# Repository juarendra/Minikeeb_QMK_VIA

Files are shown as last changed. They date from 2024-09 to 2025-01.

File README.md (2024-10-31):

# Minikeeb
a split keyboard mini based on microdox and microredox using MX Style Switch 

## Table of Content
* [Product Specsification](#product-specsification)
* [Download VIA](#download-via)
* [Load JSON File](#Load-JSON-File)
* [Link Keycode QMK](#Link-keycode-qmk)
* [Tutorial VIA Usage](#tutorial-via-usage)
* [Cara Setting Knob](#cara-setting-knob)
* [How To use MACRO](#how-to-use-macro)
* [Preview Hardware](#preview-hardware)
* [Preview VIA](#preview-via)
* [Cara Update/Upgrade Firmware](#cara-update/upgrade-firmware)
* [Documentation](#documentation)
  * [Pinout Diagram](#pinout-diagram)
  * [Dimension](#dimension)
  * [BOM](#bom)
  * [Schematic](#schematic)
  * [Example Program](#examples-program)
* [FAQ](#FAQ)

## Product Specsification
- Arduino Pro Micro Type C as Microcontroller
- QMK Firmware
- Support VIA, all key and knob can proggrammed
- RGB per Keys
- 4x Layer 
- Hotswap Switch
- 3D Case 

## Download VIA
Link Download VIA(CHOSEE BASED YOUR OS) : https://github.com/the-via/releases/releases
VIA WEB VERSION : https://usevia.app/

## Link Keycode QMK
- mouse : https://github.com/qmk/qmk_firmware/blob/master/docs/feature_mouse_keys.md
- keyboard : https://github.com/qmk/qmk_firmware/blob/master/docs/keycodes.md

## Tutorial VIA Usage
- https://docs.keeb.io/via

## Cara Setting Knob
- Untuk melakukan setting di knob perlu memasukan command berupa keycode qmk, Jadi cara nya sama dengan melakuykan setting dengan Any key seperti petunjuk pada link berikut: 
https://docs.keeb.io/via

Here's some examples:

- LALT(KC_TAB) - Sends Alt-Tab
- LCTL(KC_C) - Sends Ctrl-C
- LGUI(KC_C) - Sends Cmd-C or Win-C
- LSFT(LCTL(KC_END)) - Sends Shift-Ctrl-End
- MO(1) - Momentarily turn on layer 1
- LCA(KC_DEL) - Sends Ctrl-Alt-Del
- MT(MOD_RSFT, KC_ENT) - Sends Shift if held, Enter if tapped
- MACRO (0) - macro 0

## How To use MACRO
you can read on [this file](https://github.com/juarendra/STREAMPAD-QMK-VIA/blob/main/DOC/MACRO%20VIA%20USAGE.pdf)
or you can read on this [web](https://www.keychron.com/blogs/archived/how-to-use-via-to-program-your-keyboard)
or you can see video [youtube](https://youtu.be/GtSeo69Y0Zw)

## Preview Hardware
<p align="center">
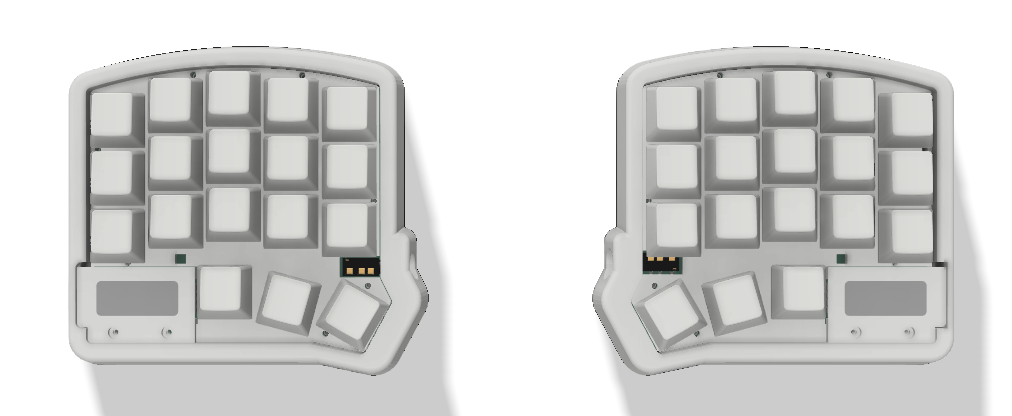
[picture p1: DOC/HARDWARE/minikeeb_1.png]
  
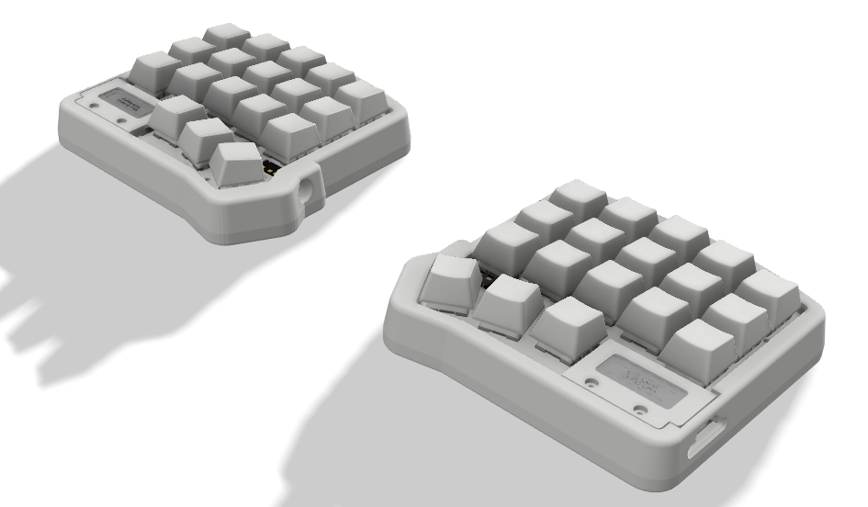
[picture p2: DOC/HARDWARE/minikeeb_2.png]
  
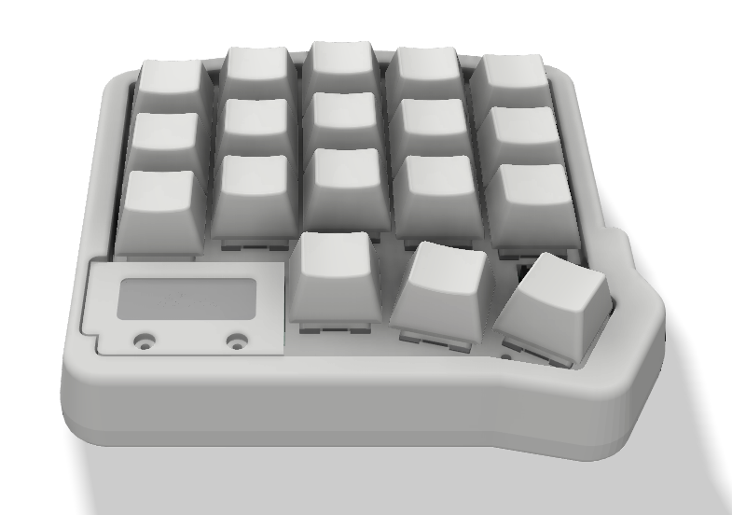
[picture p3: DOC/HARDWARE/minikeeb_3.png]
  
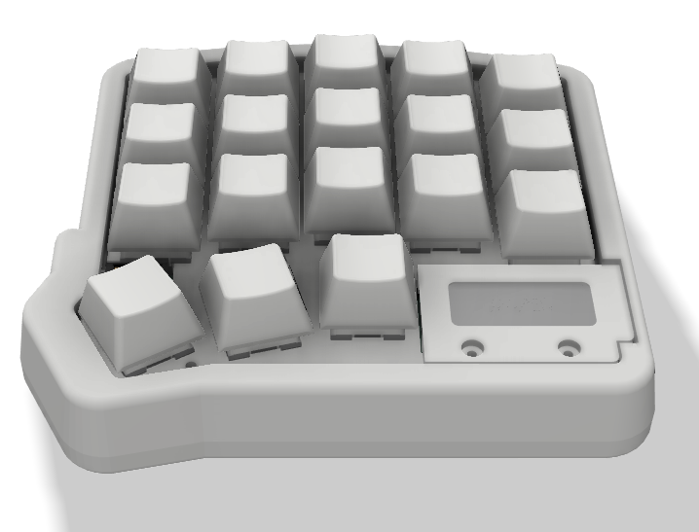
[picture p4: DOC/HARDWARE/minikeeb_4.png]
  
</p>

## Preview VIA

https://github.com/juarendra/Zeapad-Pro-QMK-VIA/assets/43043633/afd7e68e-0a54-4b18-be12-b96c0f13611a

## Cara Update/Upgrade Firmware
- Siapkan dahulu Keyboard minikeeb, kabel usb dan firmware yang ingin di update/upgrade ke keyboard anda anda
- Anda perlu melakukan flashing di masing masing sisi keyboard (kanan dan kiri)
- Siapkan Firmware yang akan digunakan untuk update/upgrade
- Download Software QMK Toolbox di [link berikut](https://github.com/qmk/qmk_toolbox/releases)
- Install Software QMK Toolbox, Install Semua drivernya. setelah siap anda dapat meload Firmware yang seblumnya. Lalu Centang Auto-Flash seperti gambar dibawah
<p align="center">
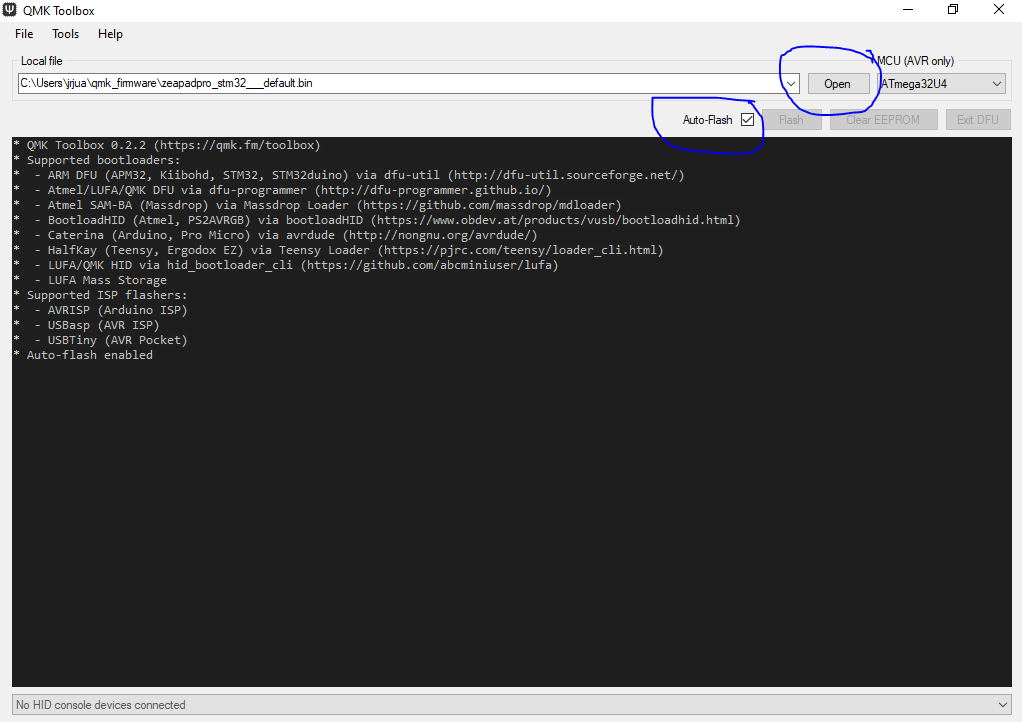
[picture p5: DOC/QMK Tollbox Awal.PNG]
  
</p>

- Lakukan flashing pada sisi kiri dahulu
- Pada minikeeb sisi kiri Colok kabel ujung usb type C ke keyboard tanpa mencolokannya dahulu ke USB PC anda
- Tekan dan tahan tombol yang berada di ujung atas kiri. lalu colokan Ujung USB yang sebelum ke USB PC anda sambil tetap menahan tombol sebelum nya sebentar
- Setelah ada bunyi/notif USB masuk. anda dapat melepaskan tombol/knobnya
- Maka secara otomatis macropad akan terflash. jika selesai maka tampilan QMK toolbox akan seperti gambar dibawah
<p align="center">
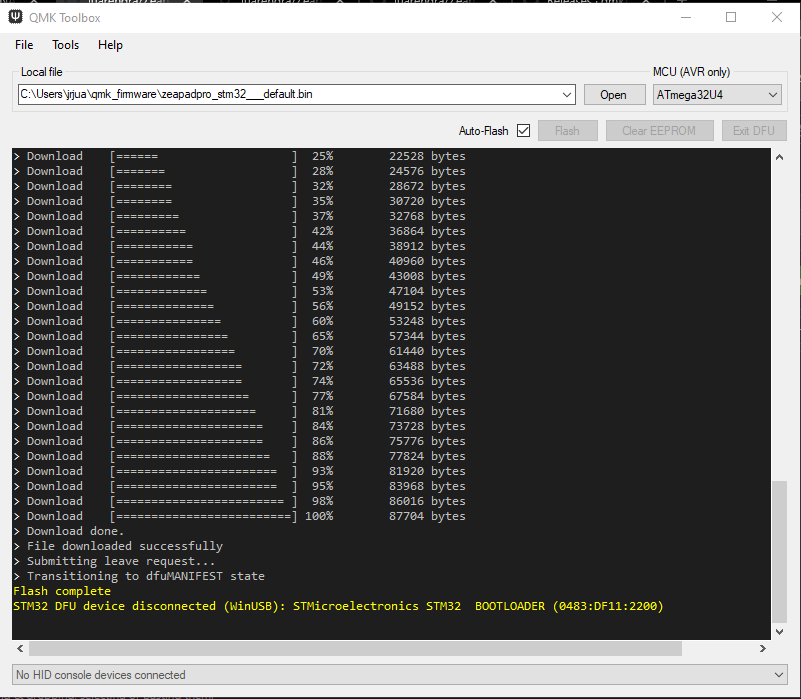
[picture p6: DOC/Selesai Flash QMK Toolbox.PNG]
  
</p>

- Lakukan flashing pada sisi kanan
- Pada minikeeb sisi kanan Colok kabel ujung usb type C ke keyboard tanpa mencolokannya dahulu ke USB PC anda
- Tekan dan tahan tombol yang berada di ujung atas kanan. lalu colokan Ujung USB yang sebelum ke USB PC anda sambil tetap menahan tombol sebelum nya sebentar
- Setelah ada bunyi/notif USB masuk. anda dapat melepaskan tombol/knobnya
- Maka secara otomatis macropad akan terflash. jika selesai maka tampilan QMK toolbox akan seperti gambar dibawah
<p align="center">
  
</p>

## Documentation
### Pinout Diagram
### Dimension
[Dimension File](https://github.com/juarendra/Minikeeb_QMK_VIA/blob/main/HARDWARE/dimension%20minikeeb.pdf)
### BOM
### Schematic
[Schematic File](https://github.com/juarendra/Minikeeb_QMK_VIA/blob/main/HARDWARE/schematic%20minikeeb.pdf)
### Example Program
[Example Firmware]()
## FAQ

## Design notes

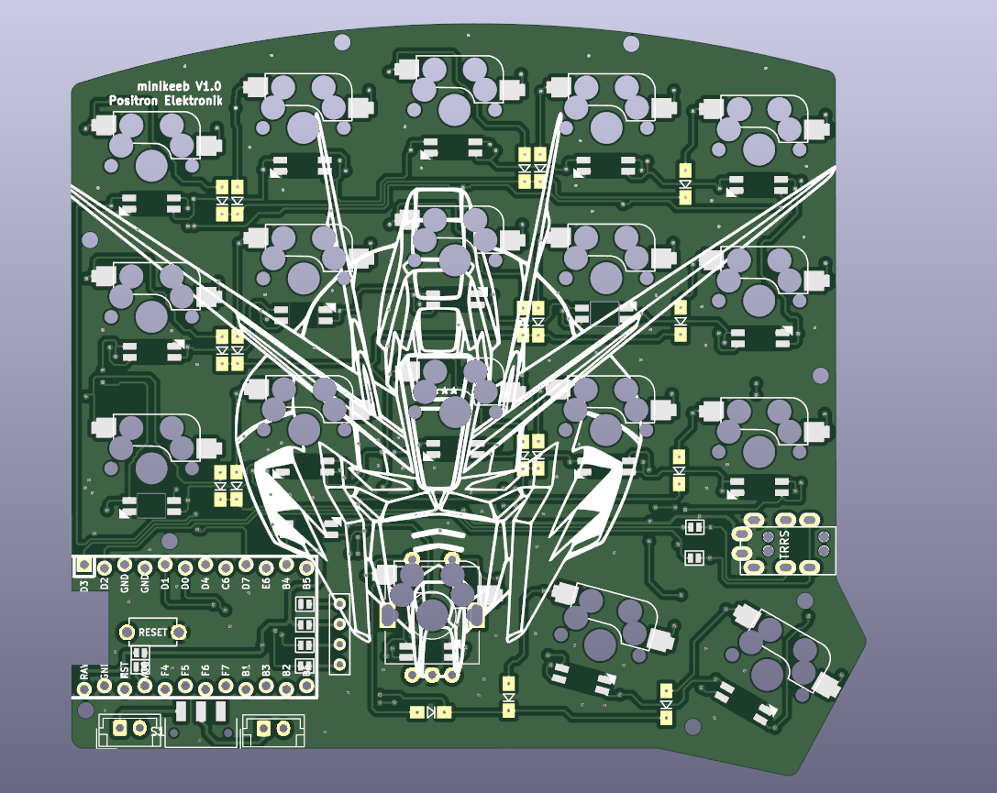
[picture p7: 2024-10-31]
DOC/HARDWARE/minikeeb_PCB.png

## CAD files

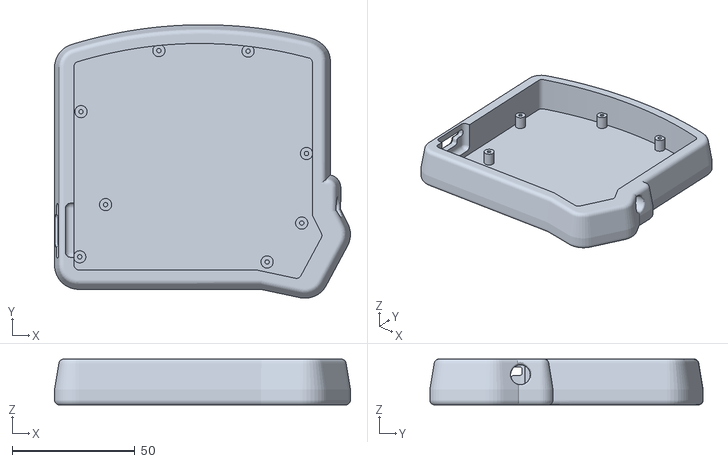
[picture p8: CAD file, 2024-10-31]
HARDWARE/3D CASE/left/minikeeb_bottom left.stl
120.5 x 111.3 x 18.7

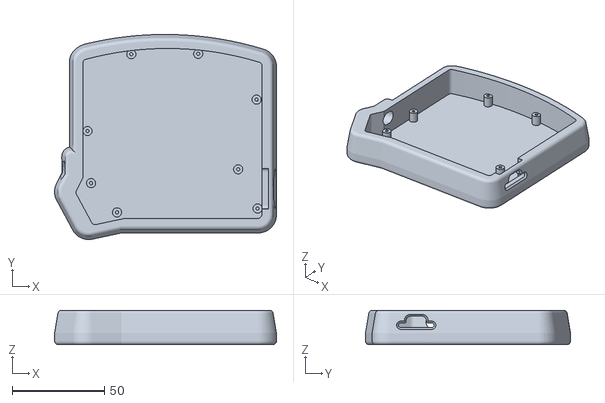
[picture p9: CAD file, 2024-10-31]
HARDWARE/3D CASE/right/minikeeb_bottom right.stl
120.5 x 111.3 x 18.7

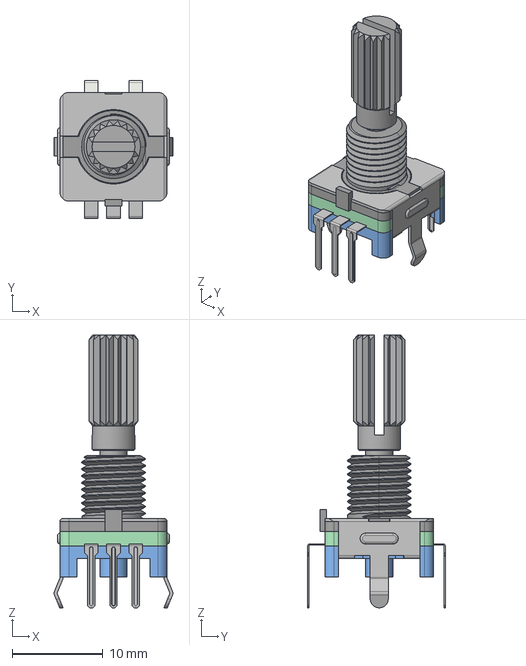
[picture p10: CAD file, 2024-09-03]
SCH-PCB/PCB/minikeeb/3d/EC11_Rotary_Encoder_Switched.step
13.1 x 15.3 x 30.1 mm

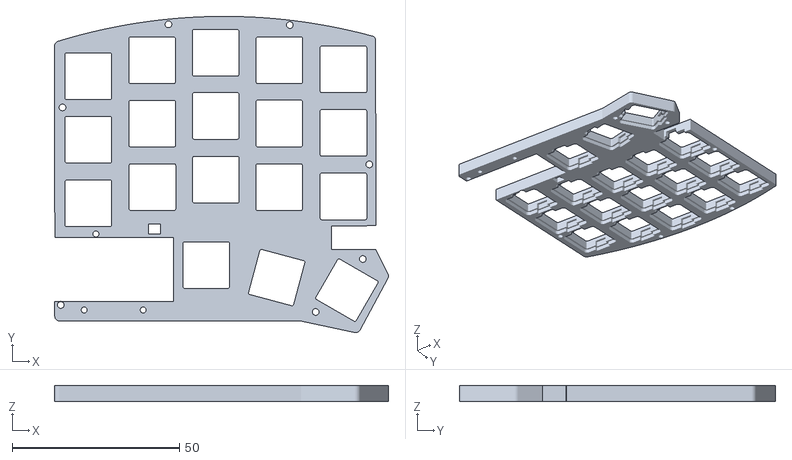
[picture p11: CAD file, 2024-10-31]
HARDWARE/3D CASE/left/minikeeb_plate left.stl
99.9 x 94.6 x 4.80

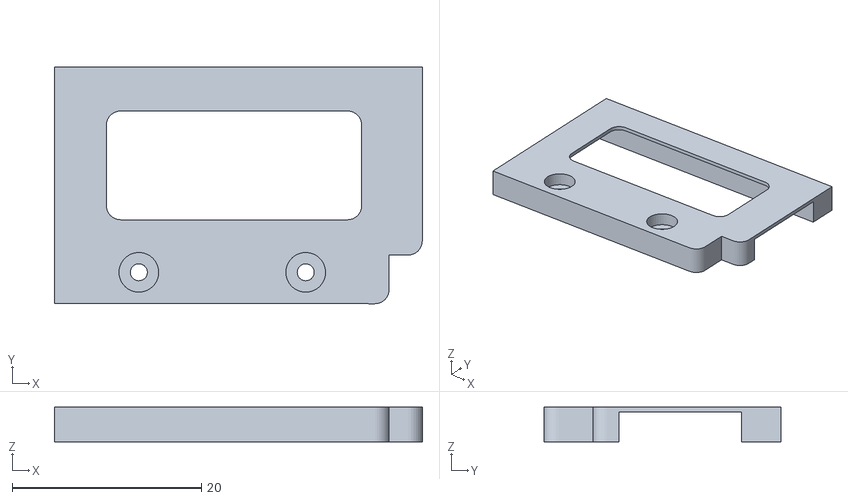
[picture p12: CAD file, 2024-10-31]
HARDWARE/3D CASE/right/minikeeb_cover oled right.stl
38.9 x 25.0 x 3.69

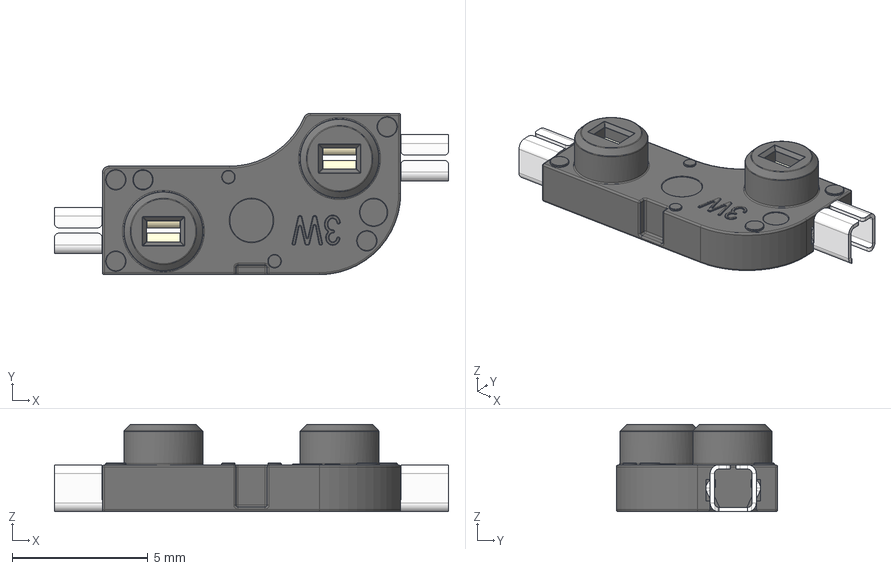
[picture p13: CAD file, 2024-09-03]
SCH-PCB/PCB/minikeeb/3d/Kailh Hotswap MX v22.step
14.5 x 5.95 x 3.22 mm

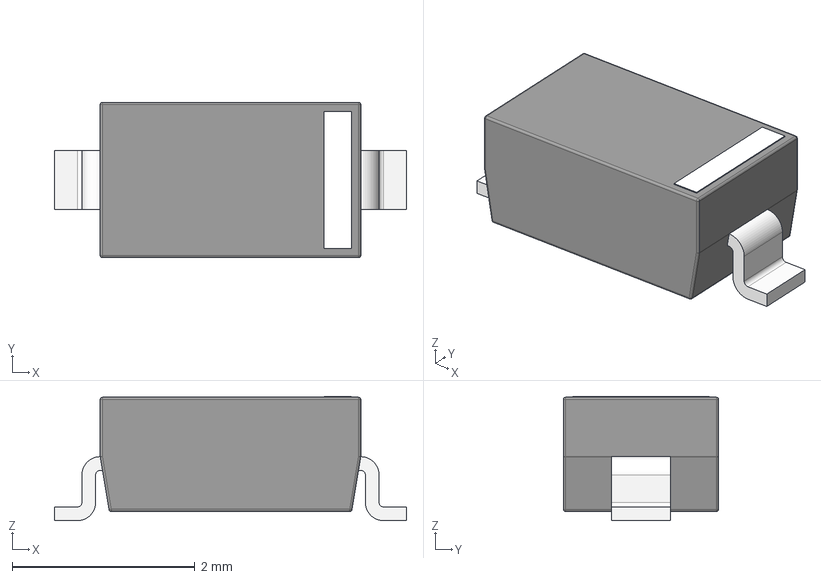
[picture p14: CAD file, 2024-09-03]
SCH-PCB/PCB/minikeeb/3d/SOD-123.step
3.85 x 1.70 x 1.36 mm

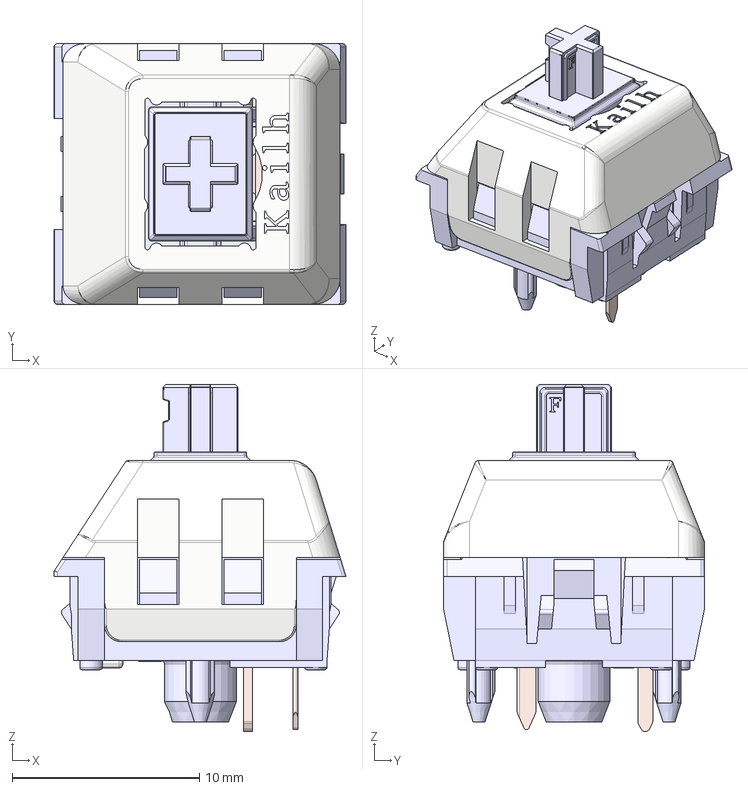
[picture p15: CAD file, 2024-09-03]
SCH-PCB/PCB/minikeeb/3d/Kailh Polia.step
15.6 x 14.0 x 18.5 mm
Housing
ThickContact
SpringContact
Stem
Lid

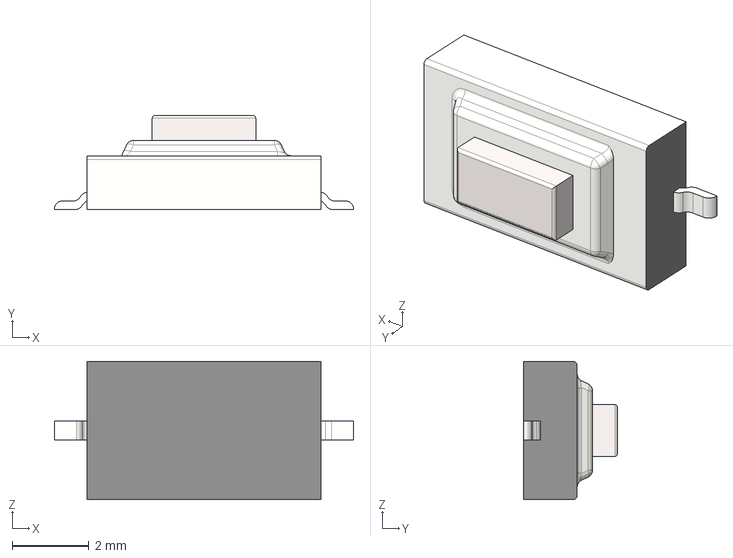
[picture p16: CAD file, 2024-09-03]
SCH-PCB/PCB/minikeeb/3d/TactileButton(6x3,5mm)_SMD.stp
7.80 x 2.45 x 3.60 mm

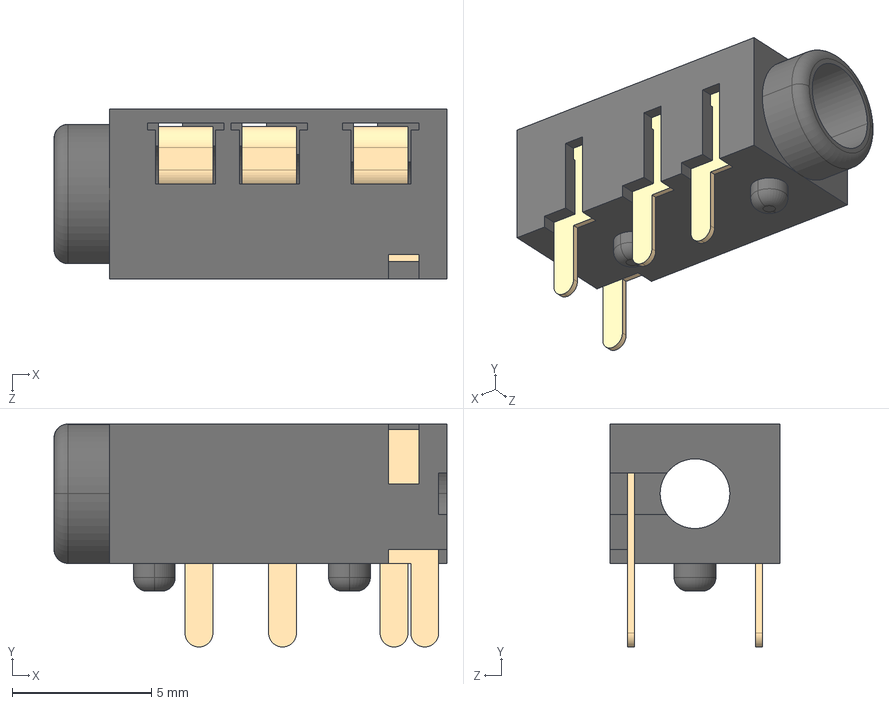
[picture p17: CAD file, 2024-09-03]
SCH-PCB/PCB/minikeeb/3d/PJ320A.STEP
14.1 x 8.00 x 6.10 mm
PJ320A蝶褲
PJ320A-Pin-A x 3
PJ320A-Pin-B

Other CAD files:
HARDWARE/3D CASE/left/minikeeb_cover oled left.stl
HARDWARE/3D CASE/right/minikeeb_plate right.stl

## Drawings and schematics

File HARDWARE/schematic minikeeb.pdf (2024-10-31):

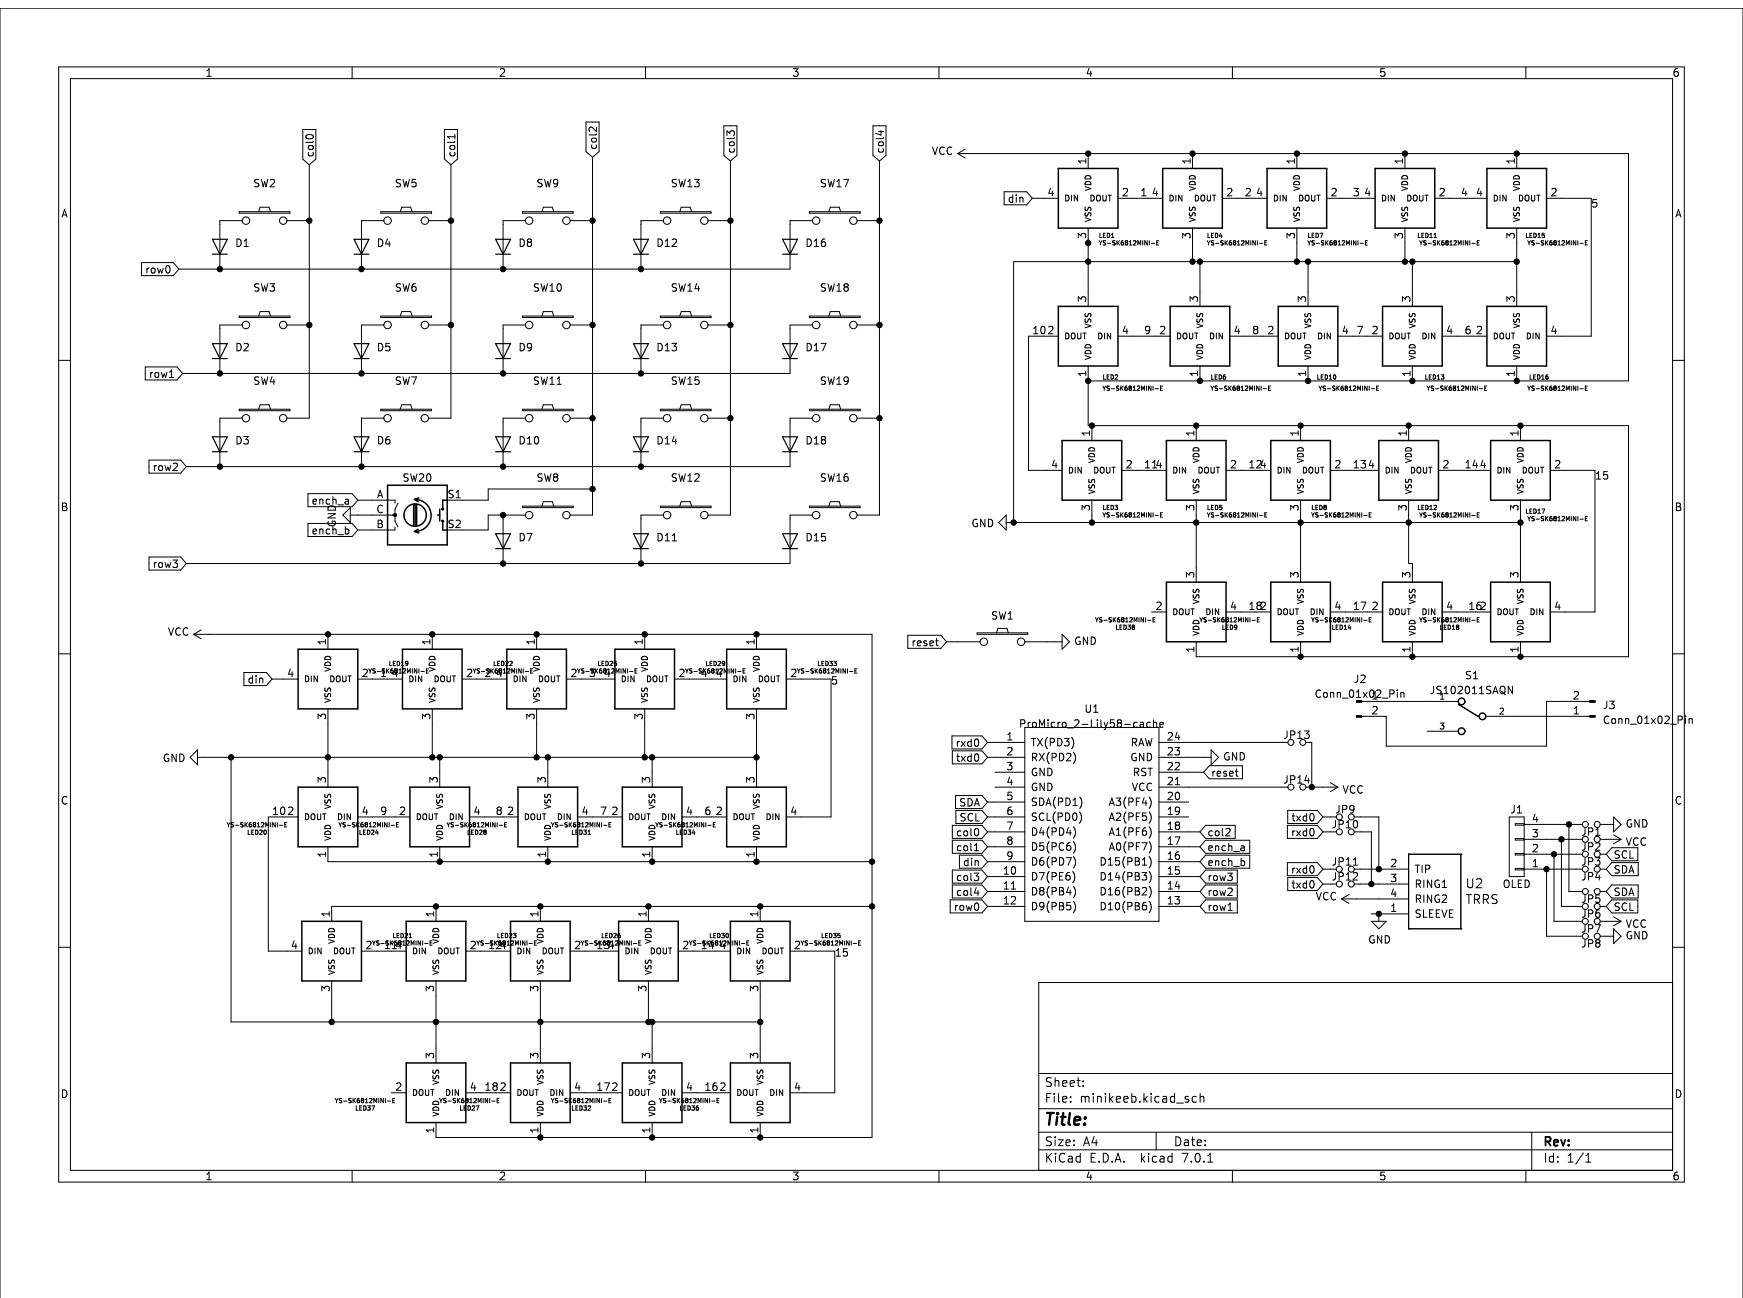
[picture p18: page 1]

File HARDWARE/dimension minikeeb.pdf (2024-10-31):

18.72
18.72 ⁹¹.12 3. SIDE VIEW | 2. SIDE VIEW | 1. TOP VIEW 4.BOTTOM VIEW ⁵. ISOMETRIC VIEW

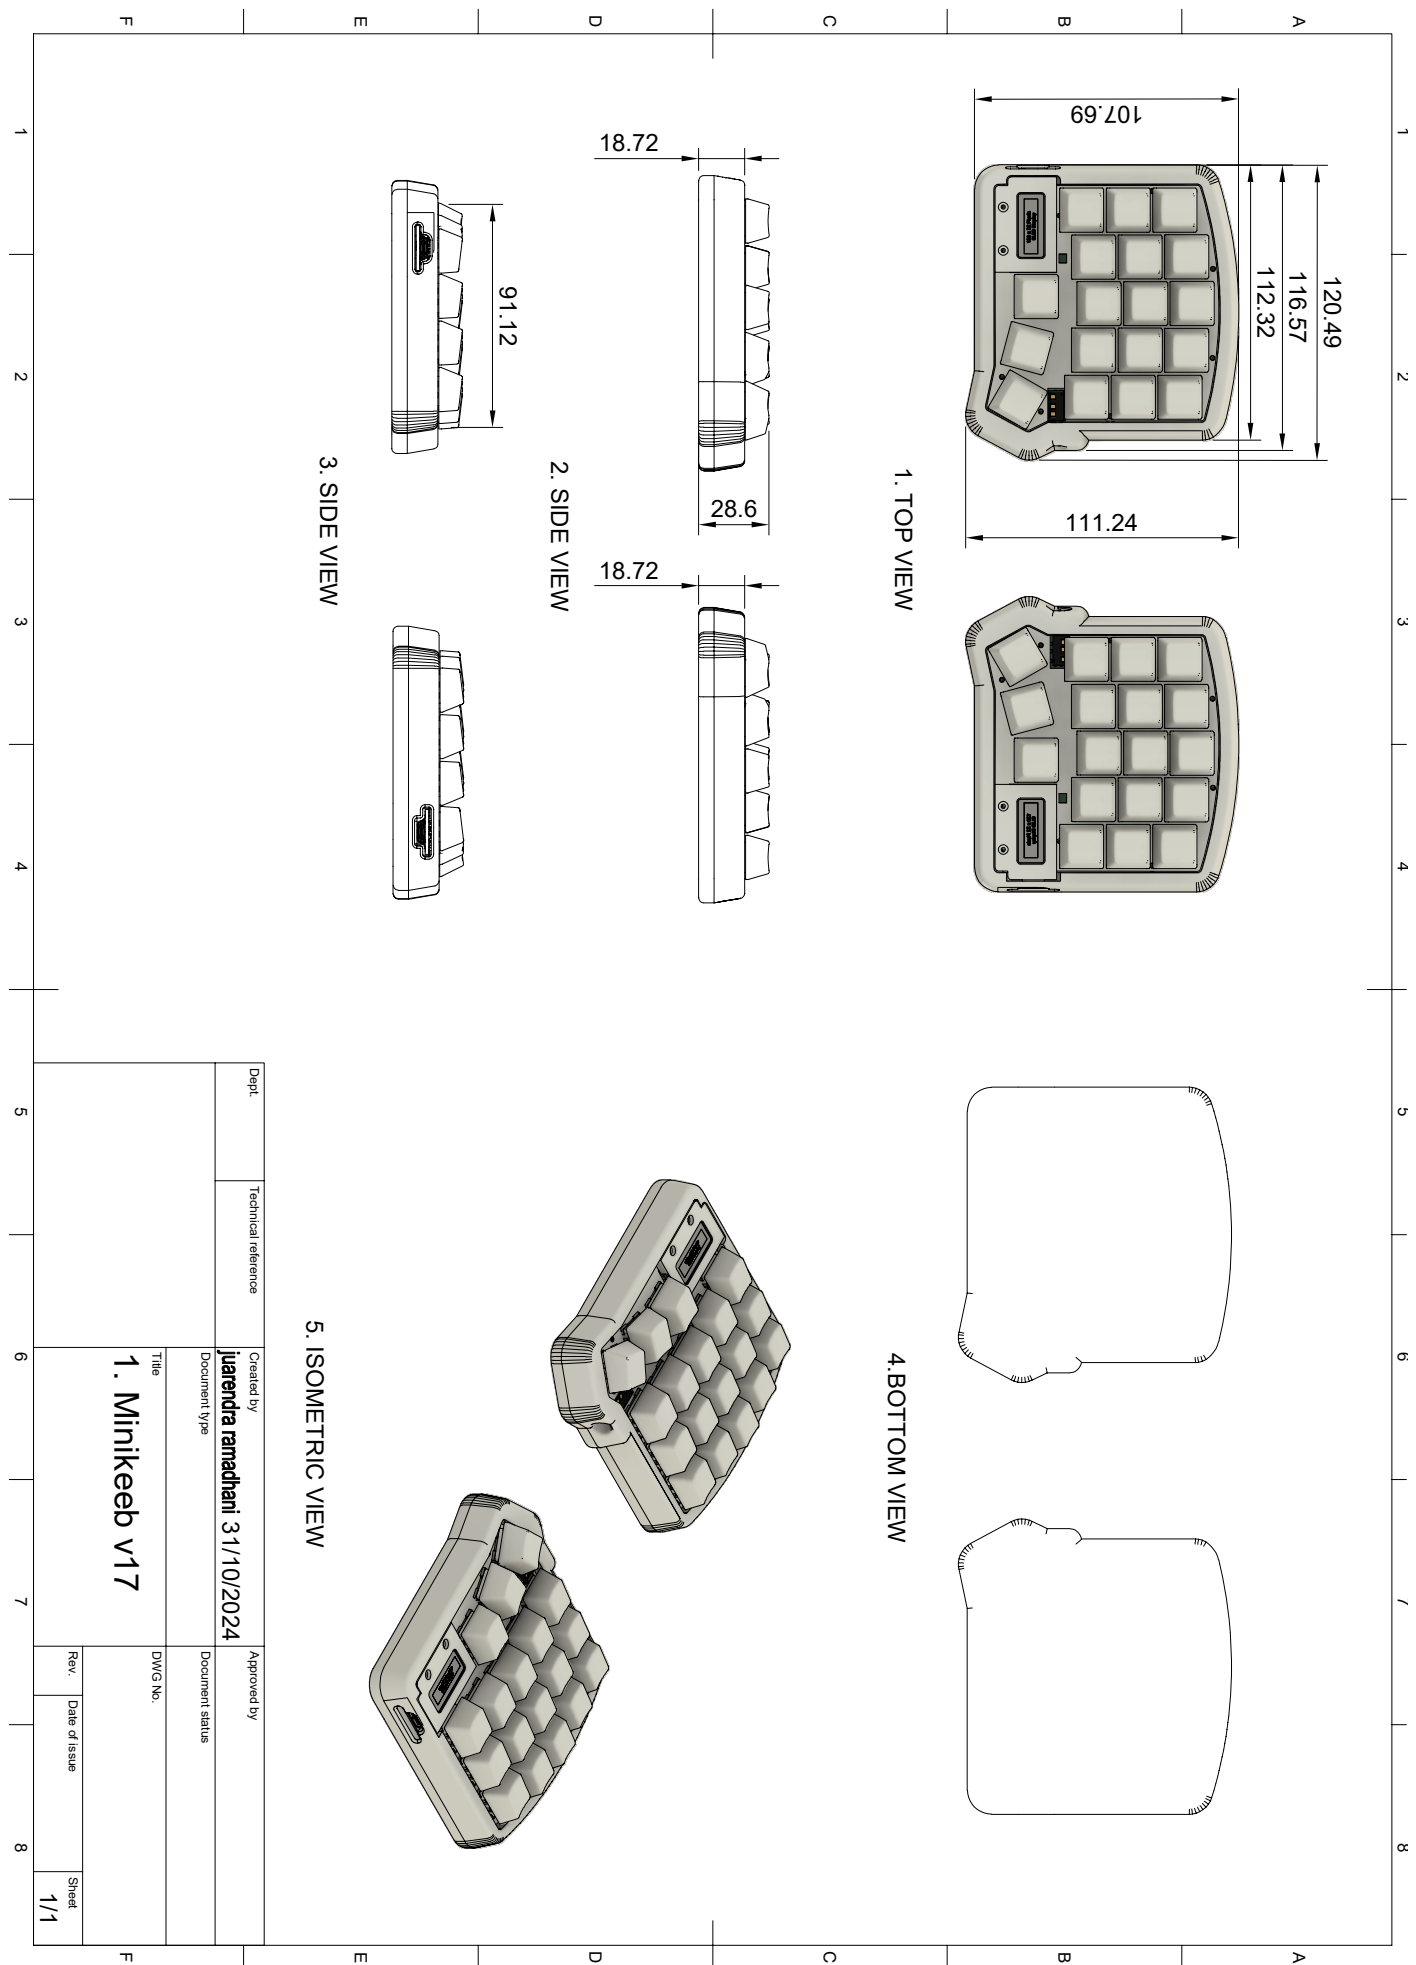
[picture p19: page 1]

1 A 2 3 4 5 6 7 8 1 2 3 4 5 6 7 8 FEDCB FEDCBA Dept. Technical reference Created by Approved by Title DWG No. Document type Document status Rev. Date of issue Sheet 31/10/2024 1/1 1. Minikeeb v17 112.32 116.57 120.49

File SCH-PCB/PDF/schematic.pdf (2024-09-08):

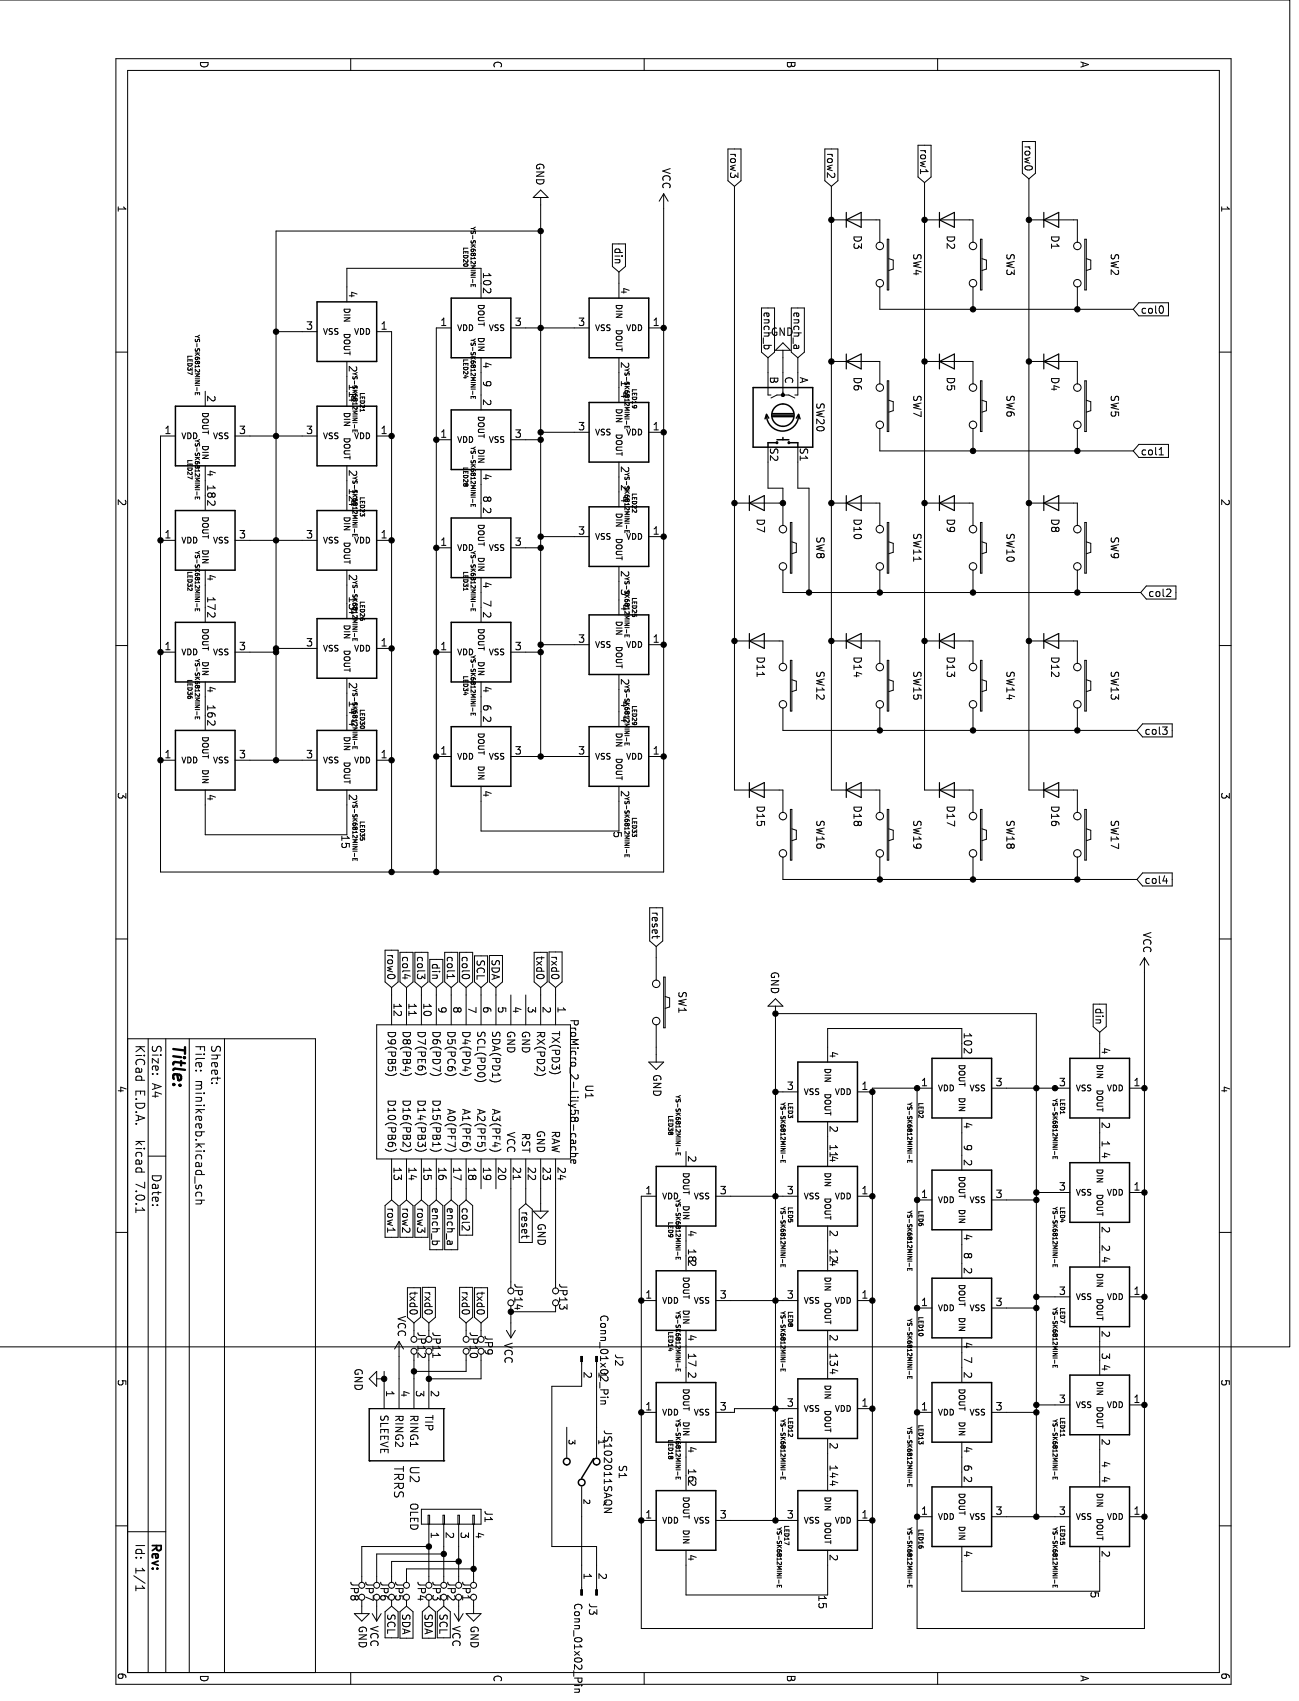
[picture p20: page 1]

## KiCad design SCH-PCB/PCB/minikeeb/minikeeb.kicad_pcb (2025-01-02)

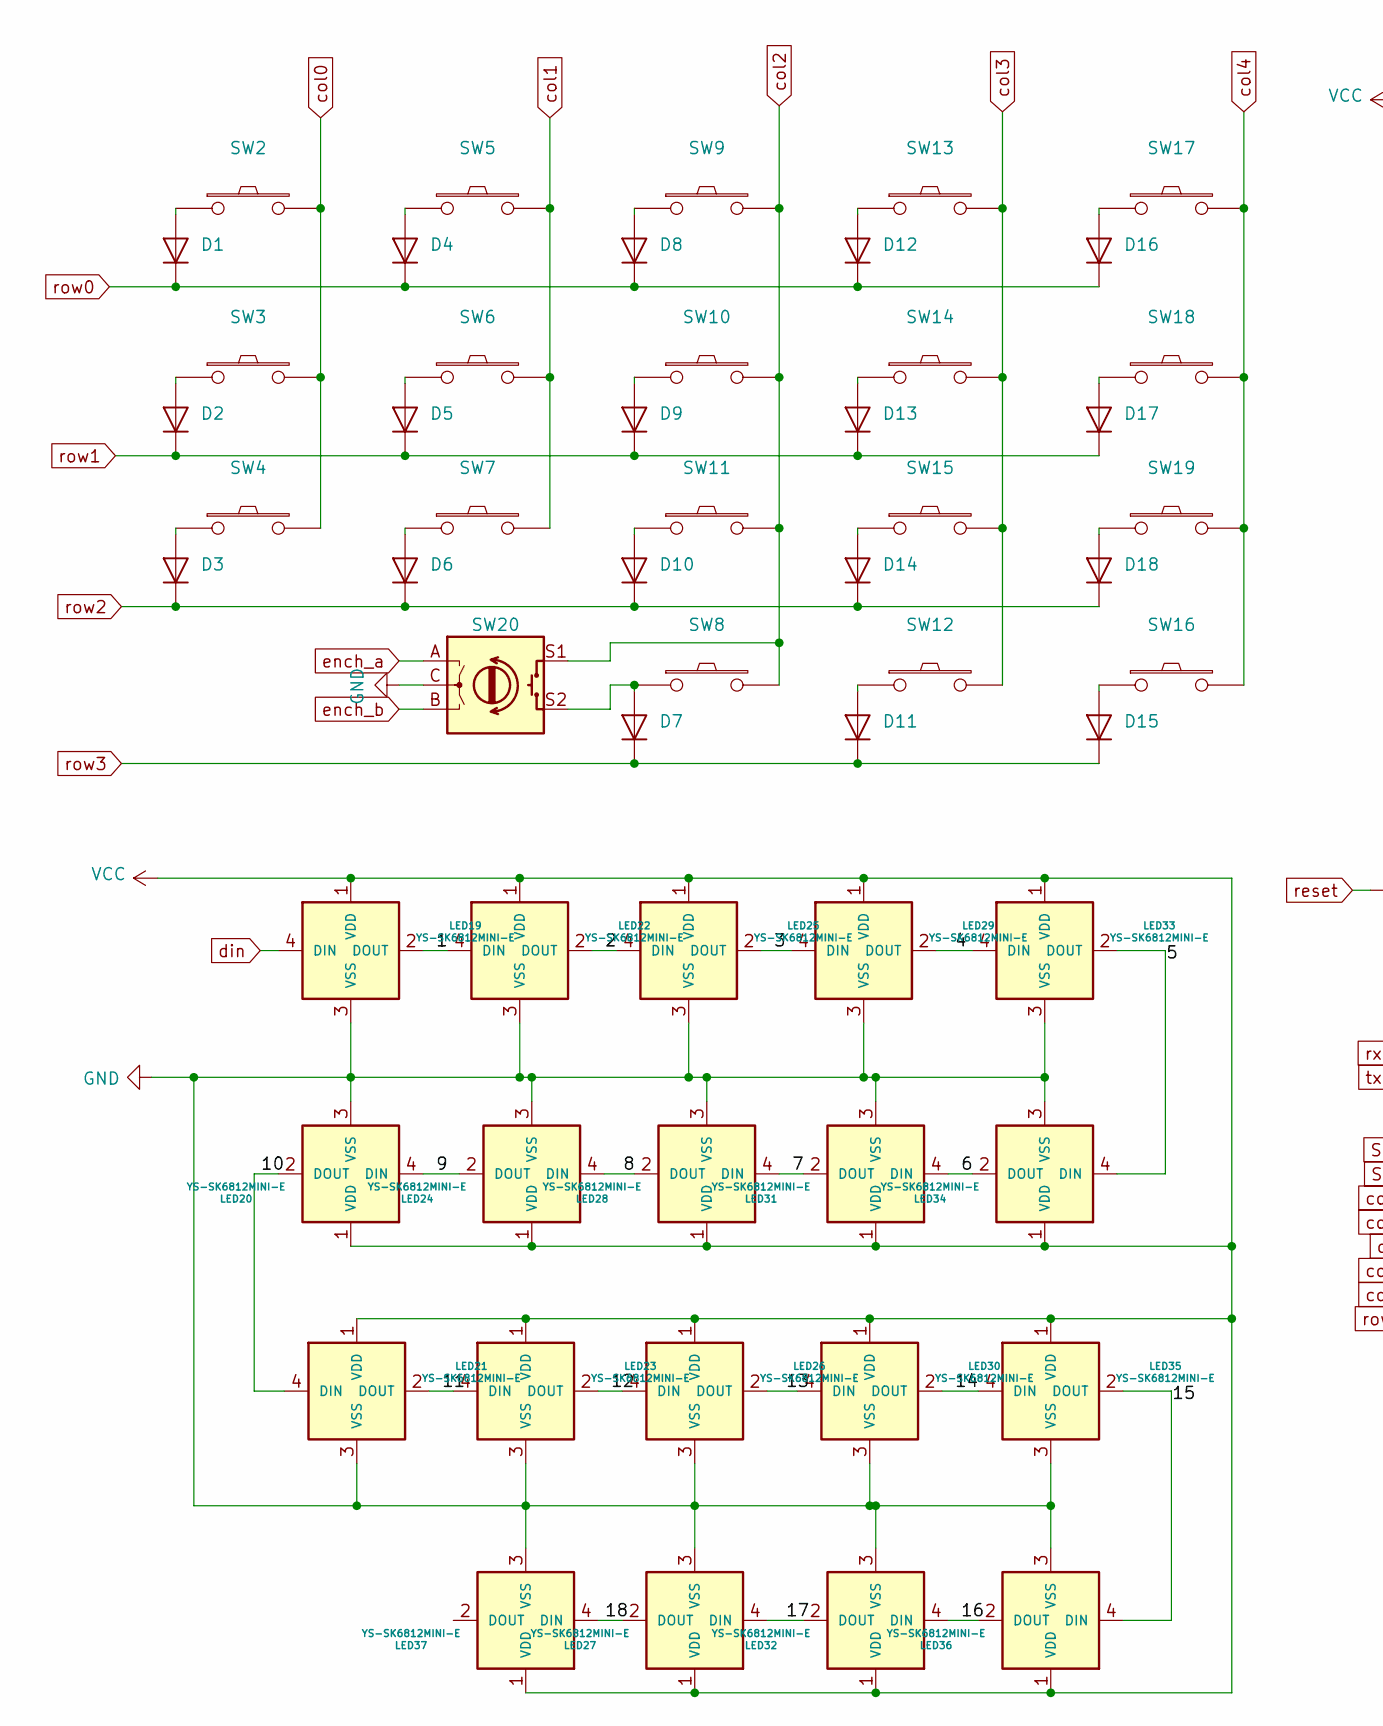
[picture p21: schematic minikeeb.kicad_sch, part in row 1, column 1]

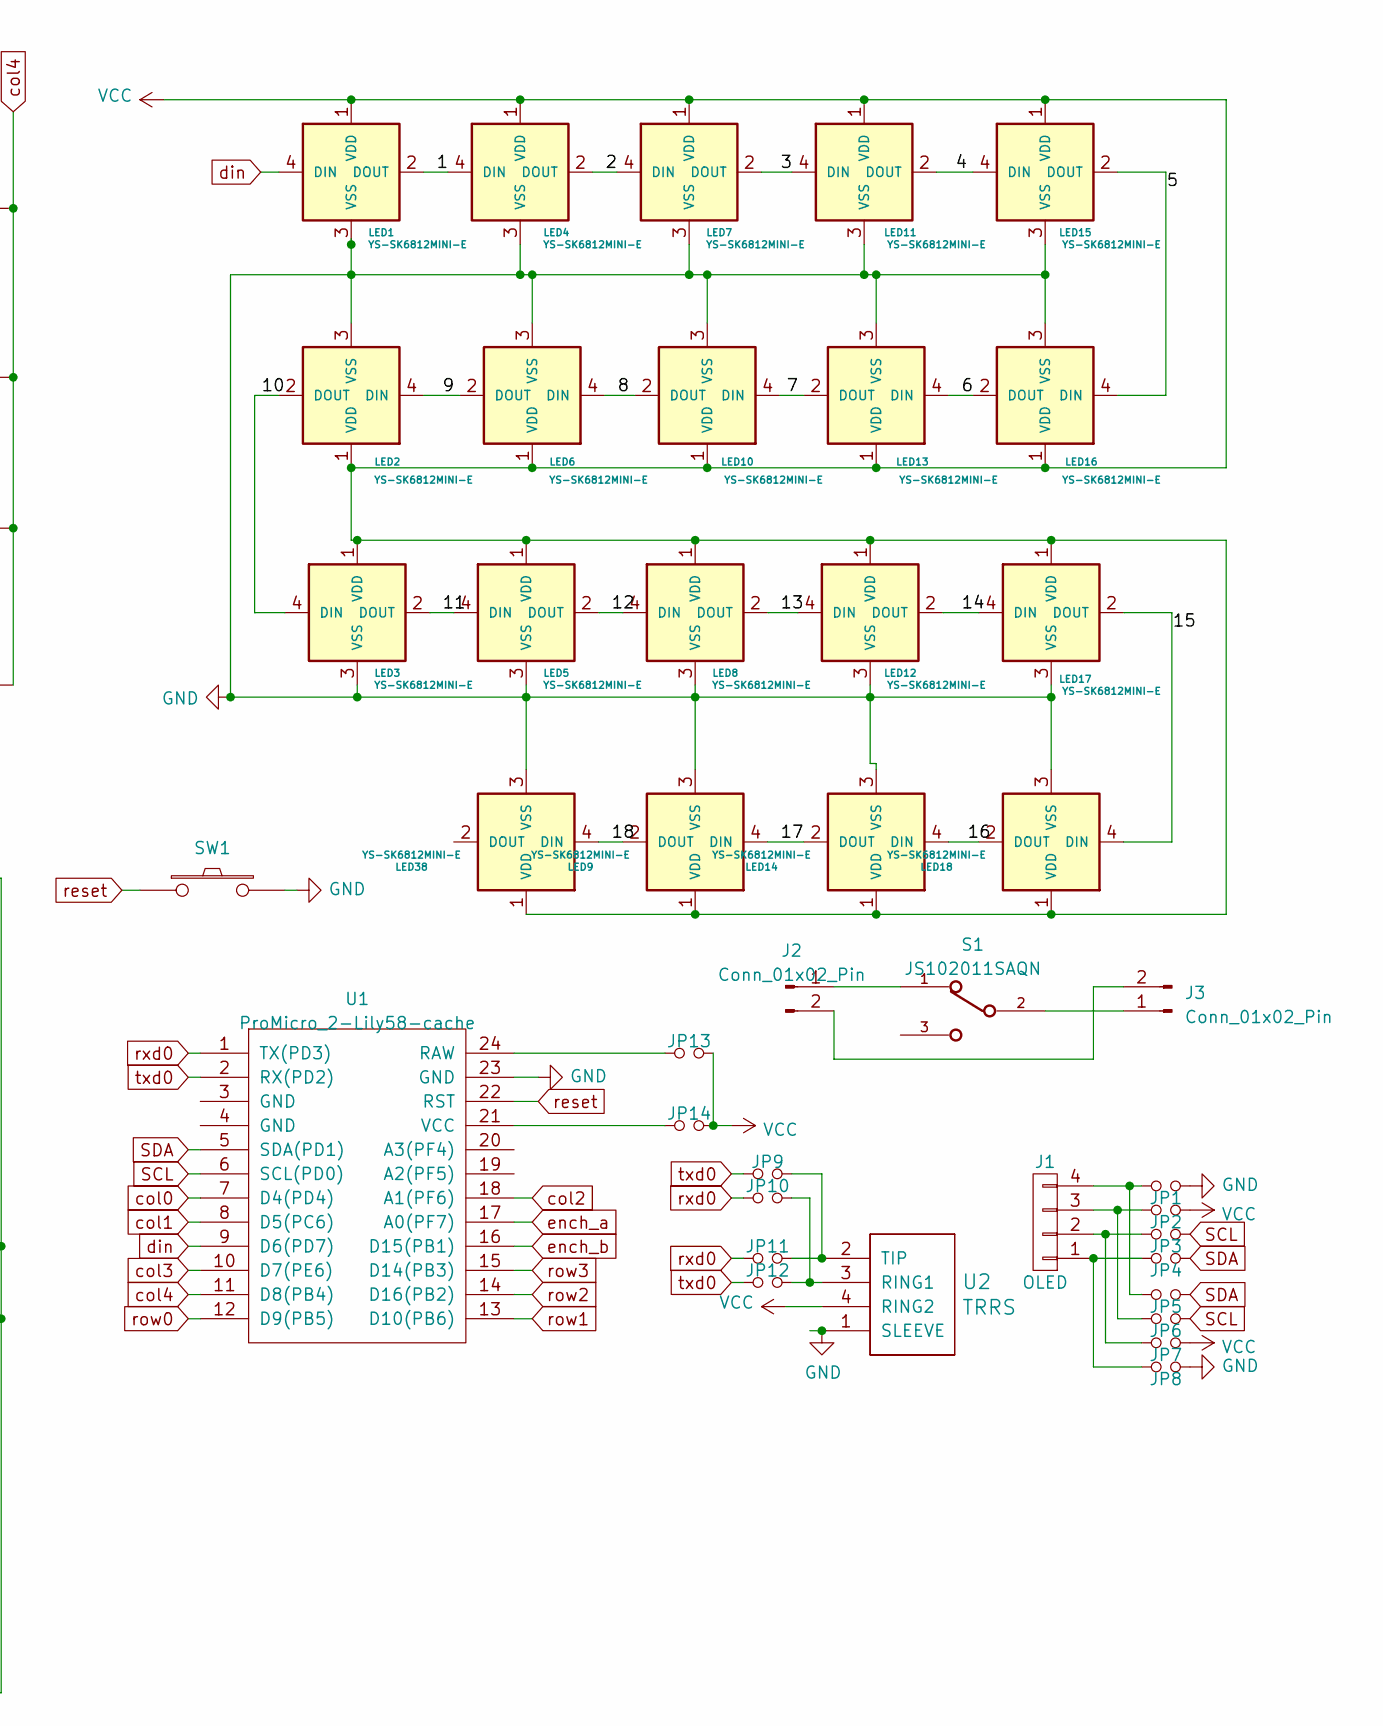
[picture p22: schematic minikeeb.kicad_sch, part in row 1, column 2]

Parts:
D1, D2, D3, D4, D5, D6, D7, D8, D9, D10, D11, D12, D13, D14, D15, D16, D17, D18: D-Lily58-cache; Diode_SOD123
J1: OLED; OLED_4Pin
J2, J3: Conn_01x02_Pin; JST_EH_B2B-EH-A_1x02_P2.50mm_Vertical
JP1, JP2, JP3, JP4, JP5, JP6, JP7, JP8, JP9, JP10, JP11, JP12, JP13, JP14: Jumper_NO_Small; Jumper
LED1, LED2, LED3, LED4, LED5, LED6, LED7, LED8, LED9, LED10, LED11, LED12, LED13, LED14, LED15, LED16, LED17, LED18, LED19, LED20, LED21, LED22, LED23, LED24, LED25, LED26, LED27, LED28, LED29, LED30, LED31, LED32, LED33, LED34, LED35, LED36, LED37, LED38: YS-SK6812MINI-E
S1: JS102011SAQN; SW_JS102011SAQN
SW1: SW_PUSH-Lily58-cache; TACT_SWITCH_TVBP06
SW2, SW3, SW4, SW5, SW6, SW7, SW8, SW9, SW10, SW11, SW12, SW13, SW14, SW15, SW16, SW17, SW18, SW19: SW_PUSH-Lily58-cache; CherryMX_Hotswap
SW20: Rotary_Encoder_Switch-Device; RotaryEncoder_Alps_EC11E-Switch_Vertical_H20mm-keebio_modif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
U1: ProMicro_2-Lily58-cache; ArduinoProMicro-ZigZag-DoubleSided
U2: TRRS; MJ-4PP-9

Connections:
/1: LED1.2 (DOUT), LED4.4 (DIN), LED19.2 (DOUT), LED22.4 (DIN)
/2: LED4.2 (DOUT), LED7.4 (DIN), LED22.2 (DOUT), LED25.4 (DIN)
/3: LED7.2 (DOUT), LED11.4 (DIN), LED25.2 (DOUT), LED29.4 (DIN)
/4: LED11.2 (DOUT), LED15.4 (DIN), LED29.2 (DOUT), LED33.4 (DIN)
/5: LED15.2 (DOUT), LED16.4 (DIN), LED33.2 (DOUT), LED34.4 (DIN)
/6: LED13.4 (DIN), LED16.2 (DOUT), LED31.4 (DIN), LED34.2 (DOUT)
/7: LED10.4 (DIN), LED13.2 (DOUT), LED28.4 (DIN), LED31.2 (DOUT)
/8: LED6.4 (DIN), LED10.2 (DOUT), LED24.4 (DIN), LED28.2 (DOUT)
/9: LED2.4 (DIN), LED6.2 (DOUT), LED20.4 (DIN), LED24.2 (DOUT)
/10: LED2.2 (DOUT), LED3.4 (DIN), LED20.2 (DOUT), LED21.4 (DIN); also elsewhere on the board
/11: LED3.2 (DOUT), LED5.4 (DIN), LED21.2 (DOUT), LED23.4 (DIN); also elsewhere on the board
/12: LED5.2 (DOUT), LED8.4 (DIN), LED23.2 (DOUT), LED26.4 (DIN)
/13: LED8.2 (DOUT), LED12.4 (DIN), LED26.2 (DOUT), LED30.4 (DIN)
/14: LED12.2 (DOUT), LED17.4 (DIN), LED30.2 (DOUT), LED35.4 (DIN)
/15: LED17.2 (DOUT), LED18.4 (DIN), LED35.2 (DOUT), LED36.4 (DIN)
/16: LED14.4 (DIN), LED18.2 (DOUT), LED32.4 (DIN), LED36.2 (DOUT)
/17: LED9.4 (DIN), LED14.2 (DOUT), LED27.4 (DIN), LED32.2 (DOUT)
/18: LED9.2 (DOUT), LED27.2 (DOUT), LED37.4 (DIN), LED38.4 (DIN)
GND: JP1.2, JP8.2, LED1.3 (VSS), LED2.3 (VSS), LED3.3 (VSS), LED4.3 (VSS), LED5.3 (VSS), LED6.3 (VSS), LED7.3 (VSS), LED8.3 (VSS), LED9.3 (VSS), LED10.3 (VSS), LED11.3 (VSS), LED12.3 (VSS), LED13.3 (VSS), LED14.3 (VSS), LED15.3 (VSS), LED16.3 (VSS), LED17.3 (VSS), LED18.3 (VSS), LED19.3 (VSS), LED20.3 (VSS), LED21.3 (VSS), LED22.3 (VSS), LED23.3 (VSS), LED24.3 (VSS), LED25.3 (VSS), LED26.3 (VSS), LED27.3 (VSS), LED28.3 (VSS), LED29.3 (VSS), LED30.3 (VSS), LED31.3 (VSS), LED32.3 (VSS), LED33.3 (VSS), LED34.3 (VSS), LED35.3 (VSS), LED36.3 (VSS), LED37.3 (VSS), LED38.3 (VSS), SW1.2, SW20.C, U1.23 (GND), U2.1 (SLEEVE); also elsewhere on the board
unnamed: D1.2 (A), SW2.1
unnamed: D2.2 (A), SW3.1
unnamed: D3.2 (A), SW4.1
unnamed: D4.2 (A), SW5.1
unnamed: D5.2 (A), SW6.1
unnamed: D6.2 (A), SW7.1
unnamed: D7.2 (A), SW8.1, SW20.S2
unnamed: D8.2 (A), SW9.1
unnamed: D9.2 (A), SW10.1
unnamed: D10.2 (A), SW11.1
unnamed: D11.2 (A), SW12.1
unnamed: D12.2 (A), SW13.1
unnamed: D13.2 (A), SW14.1
unnamed: D14.2 (A), SW15.1
unnamed: D15.2 (A), SW16.1
unnamed: D16.2 (A), SW17.1
unnamed: D17.2 (A), SW18.1
unnamed: D18.2 (A), SW19.1
unnamed: J1.1, JP4.1, JP8.1
unnamed: J1.2, JP3.1, JP7.1
unnamed: J1.3, JP2.1, JP6.1
unnamed: J1.4, JP1.1, JP5.1
unnamed: J2.1, S1.1
unnamed: J2.2, J3.2
unnamed: J3.1, S1.2
unnamed: JP13.2, U1.24 (RAW)
unnamed: JP14.2, U1.21 (VCC)
unnamed: JP10.1, JP12.1, U2.3 (RING1)
unnamed: JP9.1, JP11.1, U2.2 (TIP)
SCL: JP3.2, JP6.2, U1.6 (SCL(PD0))
SDA: JP4.2, JP5.2, U1.5 (SDA(PD1))
VCC: JP2.2, JP7.2, JP13.1, JP14.1, LED1.1 (VDD), LED2.1 (VDD), LED3.1 (VDD), LED4.1 (VDD), LED5.1 (VDD), LED6.1 (VDD), LED7.1 (VDD), LED8.1 (VDD), LED9.1 (VDD), LED10.1 (VDD), LED11.1 (VDD), LED12.1 (VDD), LED13.1 (VDD), LED14.1 (VDD), LED15.1 (VDD), LED16.1 (VDD), LED17.1 (VDD), LED18.1 (VDD), LED19.1 (VDD), LED20.1 (VDD), LED22.1 (VDD), LED23.1 (VDD), LED24.1 (VDD), LED25.1 (VDD), LED26.1 (VDD), LED27.1 (VDD), LED28.1 (VDD), LED29.1 (VDD), LED30.1 (VDD), LED31.1 (VDD), LED32.1 (VDD), LED33.1 (VDD), LED34.1 (VDD), LED35.1 (VDD), LED36.1 (VDD), LED37.1 (VDD), LED38.1 (VDD), U2.4 (RING2); also elsewhere on the board
col0: SW2.2, SW3.2, SW4.2, U1.7 (D4(PD4))
col1: SW5.2, SW6.2, SW7.2, U1.8 (D5(PC6))
col2: SW8.2, SW9.2, SW10.2, SW11.2, SW20.S1, U1.18 (A1(PF6))
col3: SW12.2, SW13.2, SW14.2, SW15.2, U1.10 (D7(PE6))
col4: SW16.2, SW17.2, SW18.2, SW19.2, U1.11 (D8(PB4))
din: LED1.4 (DIN), LED19.4 (DIN), U1.9 (D6(PD7))
ench_a: SW20.A, U1.17 (A0(PF7))
ench_b: SW20.B, U1.16 (D15(PB1))
reset: SW1.1, U1.22 (RST)
row0: D1.1 (K), D4.1 (K), D8.1 (K), D12.1 (K), D16.1 (K), U1.12 (D9(PB5))
row1: D2.1 (K), D5.1 (K), D9.1 (K), D13.1 (K), D17.1 (K), U1.13 (D10(PB6))
row2: D3.1 (K), D6.1 (K), D10.1 (K), D14.1 (K), D18.1 (K), U1.14 (D16(PB2))
row3: D7.1 (K), D11.1 (K), D15.1 (K), U1.15 (D14(PB3))
rxd0: JP10.2, JP11.2, U1.1 (TX(PD3))
txd0: JP9.2, JP12.2, U1.2 (RX(PD2))

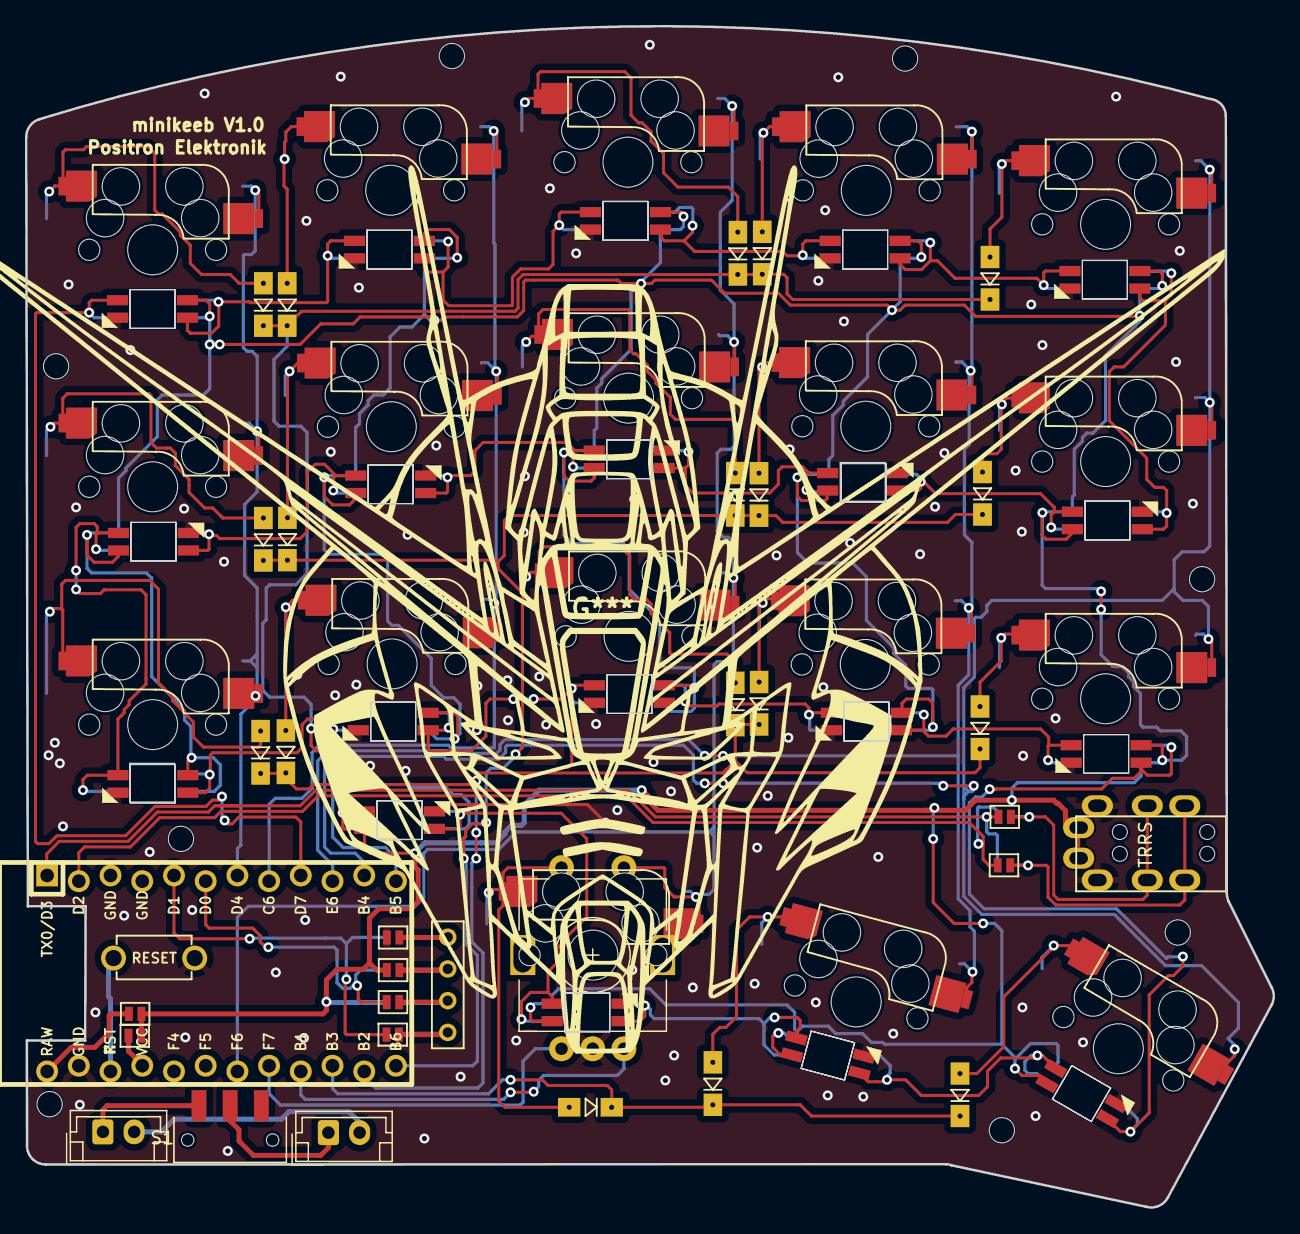
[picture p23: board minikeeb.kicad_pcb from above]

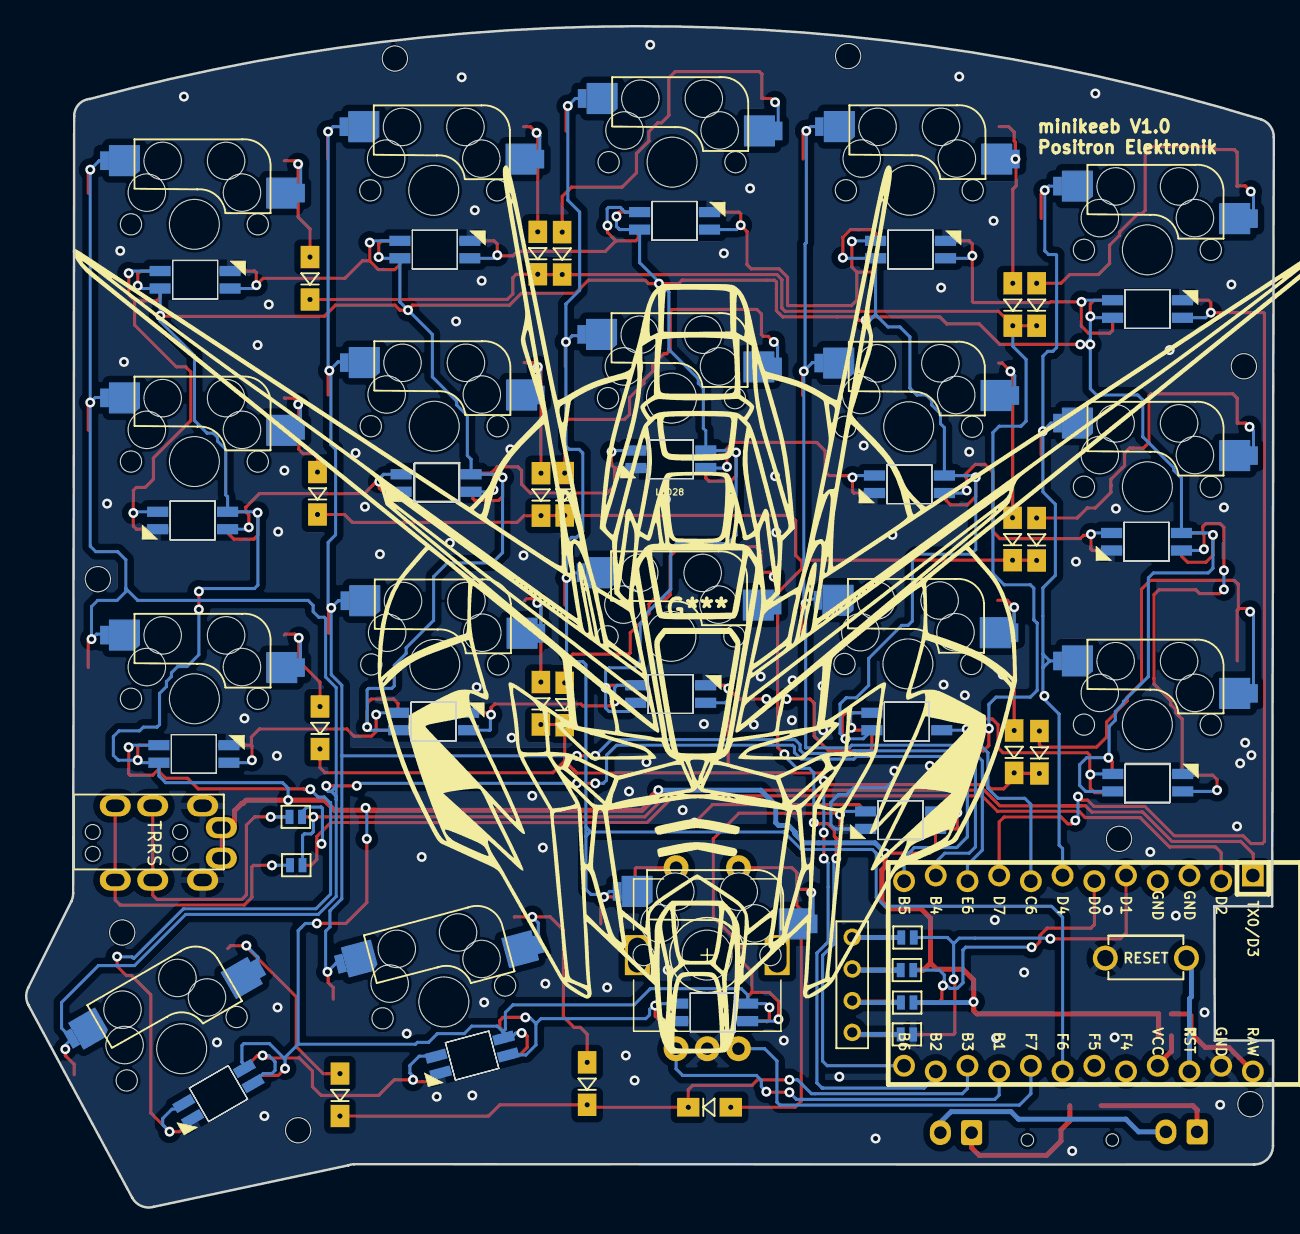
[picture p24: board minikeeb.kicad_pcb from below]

Board: 2 copper layers, 99.9 x 94.6 mm, 96 parts (26 on the bottom side), 66 nets.

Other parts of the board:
locked: YS-SK6812MINI-E

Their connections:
/10: locked.4 (DIN); also elsewhere on the board
/11: locked.2 (DOUT); also elsewhere on the board
GND: locked.3 (VSS); also elsewhere on the board
VCC: locked.1 (VDD); also elsewhere on the board

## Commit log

2024-08-29 FEAT: add firt pcb and sch design file
    [minikeeb.kicad_pcb, minikeeb.kicad_sch, minikeeb.sch]
2024-09-01 DOC: update readme
    [minikeeb.kicad_pcb, minikeeb.kicad_sch]
2024-09-01 FEAT: updaet PCB
    [minikeeb.kicad_pcb]
2024-09-03 FEAT: change microcontroller to promicro layout
    [EC11_Rotary_Encoder_Switched.step, Kailh Hotswap MX v22.step, Kailh Polia.step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]
2024-09-03 FEAT: add logo and name
    [minikeeb-B_Cu.gbr, minikeeb-B_Mask.gbr, minikeeb-B_Paste.gbr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]
2024-09-03 FEAT: add file render 3d pcb
    [minikeeb.kicad_pcb]
2024-09-03 FEAT: add bolt hole
    [minikeeb-B_Cu.gbr, minikeeb-B_Mask.gbr, minikeeb-B_Paste.gbr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]
2024-09-05 FEAT: update pcb
    [minikeeb-B_Cu.gbr, minikeeb-B_Mask.gbr, minikeeb-B_Paste.gbr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]
2024-09-08 FEAT: update pcb for vcc selection
    [minikeeb-B_Cu.gbr, minikeeb-B_Mask.gbr, minikeeb-B_Paste.gbr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]
2024-09-17 FEAT: add 3d file plate
    [minikeeb_plate_kanan.stl, minikeeb_plate_kiri.stl]
2024-09-17 FEAT: add image 3d pcb with plate
2024-09-17 FEAT: add image 3d pcb with componnet
2024-09-18 FEAT : update hole for plate design
    [minikeeb-B_Cu.gbr, minikeeb-B_Mask.gbr, minikeeb-B_Paste.gbr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]
2024-10-18 FIX fix dimension PCB
    [minikeeb-B_Cu.gbr, minikeeb-B_Mask.gbr, minikeeb-B_Paste.gbr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]
2024-10-31 FEAT: update keyboard pcb case and documentation
    [minikeeb.kicad_pcb, minikeeb_bottom left.stl, minikeeb_bottom right.stl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]
2024-10-31 DOC: add dimension file and schematic
2024-10-31 FEAT: add gerber file
    [minikeeb-B_Cu.gbr, minikeeb-B_Mask.gbr, minikeeb-B_Paste.gbr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]
2024-10-31 FEAT: add pcb image
